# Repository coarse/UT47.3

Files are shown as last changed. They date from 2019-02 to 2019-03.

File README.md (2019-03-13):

# UT47.3
STM32 40% Keyboard PCB

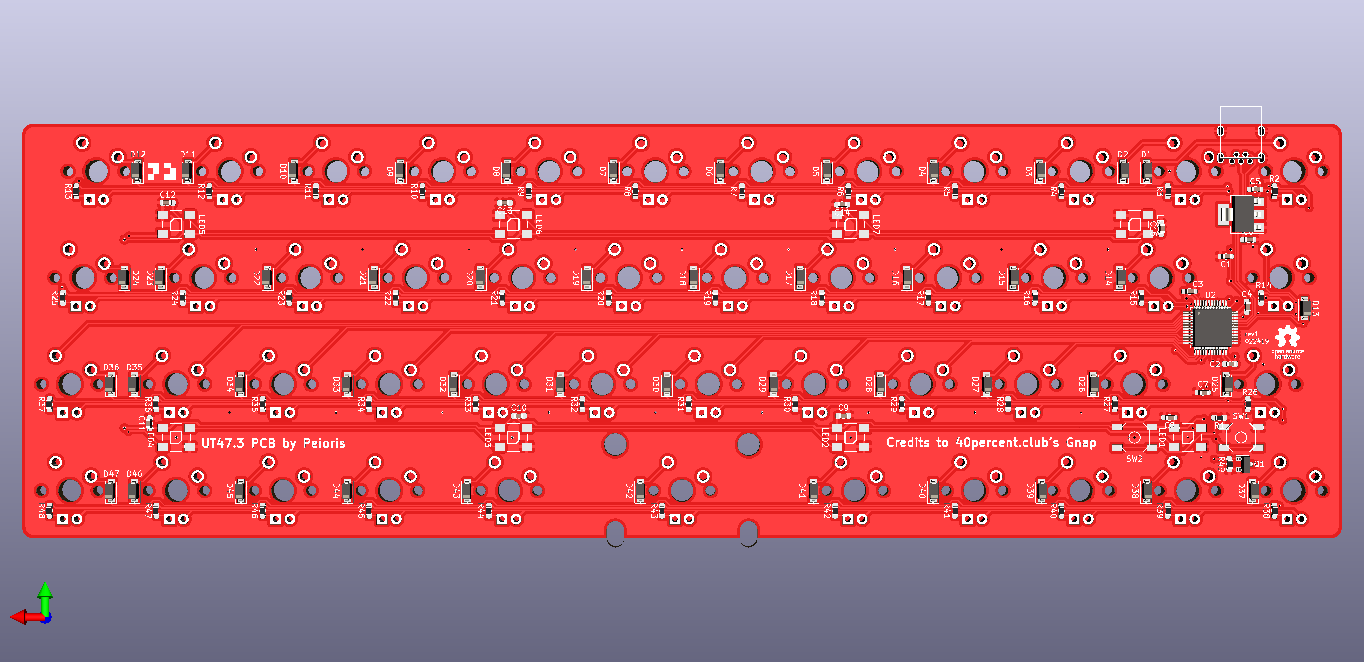
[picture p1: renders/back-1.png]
Render


Keyboard Layout Editor layout: [Layout](http://www.keyboard-layout-editor.com/#/gists/ddc8fda154c2c93ac26e38cd5da5988e)

Made with permission from [KeyHive](https://keyhive.xyz/).

The design is inspired by 40percent.club's Gnap keyboard, which is licensed under [CC BY-SA 4.0](https://creativecommons.org/licenses/by-sa/4.0/).



## Notes

At the moment, UT 47.3 is not compatible with most UT47.2 and UT47 cases. A number of differences from the two other PCBs are as follow:

1. USB port location
  - UT47.3's USB port is located at the top left part of the case. UT47 and UT47.2's USB port is located at the top right part of the case. This will be fixed in another revision
  
2. ARM Microcontroller
  - Unlike UT47 and UT47.2, UT47.3 uses an ARM microcontroller instead of an AVR microcontroller. Specifically, the UT47.3 uses an STM32F072 microcontroller due to not needing an external crystal to use it as an HID keyboard device which keeps costs low.
  
2. Reset switch location/s
  - UT47.3, powered by an STM32 chip, needs two physical switches for reset and entering DFU. Because of that, the location of the switches on the UT47.3 are differnet.
  
3. RGB underglow LED
  - UT47.3 was meant to be a budget PCB therefore the number of underglow LEDs were reduced to 8.
  
4. Single color backlight
  - UT47.3 introduces a simple single-zone backlighting.

5. Non-hotswap
  - Because backlighting is present, using hotswap modules is not an option for this PCB.

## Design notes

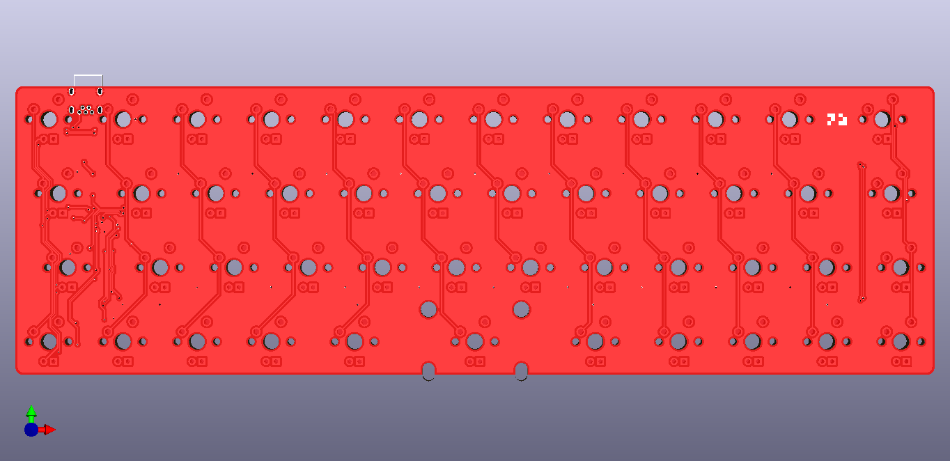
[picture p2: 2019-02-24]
renders/front-1.png

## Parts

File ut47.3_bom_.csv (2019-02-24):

Component | Description | Part | References | Value | Footprint | Quantity Per PCB | Datasheet
1 |  | C | C2 C3 C4 C7 C9 C11 C13 C14 C15 | 100nF | C_0603_1608Metric_Pad1.05x0.95mm_HandSolder | 9
2 |  | C | C5 C6 | 10uF | C_0603_1608Metric_Pad1.05x0.95mm_HandSolder | 2
3 |  | C | C1 C8 C10 C12 | 4.7uF | C_0603_1608Metric_Pad1.05x0.95mm_HandSolder | 4
4 |  | D | D1 D2 D3 D4 D5 D6 D7 D8 D9 D10 D11 D12 D13 D14 D15 D16 D17 D18 D19 D20 D21 D22 D23 D24 D25 D26 D27 D28 D29 D30 D31 D32 D33 D34 D35 D36 D37 D38 D39 D40 D41 D42 D43 D44 D45 D46 D47 | D | D_SOD-123 | 47
5 | RGB LED with integrated controller | WS2812B | LED1 LED2 LED3 LED4 LED5 LED6 LED7 LED8 | WS2812B | WS2812B | 8
6 |  | MX-1.25U | MX13 MX24 MX41 MX43 | MX-1.25U | MXOnly-1.25U | 4
7 |  | MX-1.5U | MX12 MX25 | MX-1.5U | MXOnly-1.5U | 2
8 |  | MX-1U | MX1 MX2 MX3 MX4 MX5 MX6 MX7 MX8 MX9 MX10 MX11 MX14 MX15 MX16 MX17 MX18 MX19 MX20 MX21 MX22 MX23 MX26 MX27 MX28 MX29 MX30 MX31 MX32 MX33 MX34 MX35 MX36 MX37 MX38 MX39 MX40 MX44 MX45 MX46 MX47 | MX-1U | MXOnly-1U | 40
9 |  | MX-2U | MX42 | MX-2U | MXOnly-2U-ReversedStabilizers | 1
10 | 0.2A Ic, 40V Vce, Small Signal NPN Transistor, SOT-23 | MMBT3904 | Q1 | MMBT3904 | SOT-23 | 1 | https://www.fairchildsemi.com/datasheets/2N/2N3904.pdf
11 |  | R | R1 R49 | 10k | R_0603_1608Metric_Pad1.05x0.95mm_HandSolder | 2
12 |  | R | R2 R3 R4 R5 R6 R7 R8 R9 R10 R11 R12 R13 R14 R15 R16 R17 R18 R19 R20 R21 R22 R23 R24 R25 R26 R27 R28 R29 R30 R31 R32 R33 R34 R35 R36 R37 R38 R39 R40 R41 R42 R43 R44 R45 R46 R47 R48 | 470 | R_0603_1608Metric_Pad1.05x0.95mm_HandSolder | 47
13 |  | SW | SW1 SW2 | K2-1187SQ-A4SW-06 | K2-1187SQ-A4SW-06 | 2
14 |  | LDO_REG | U1 | LD1117AG-33-AA3-A-R | SOT-223 | 1
15 | ARM Cortex-M0 MCU, 128KB flash, 16KB RAM, 48MHz, 2-3.6V, 37 GPIO, LQFP-48 | STM32F072CBTx | U2 | STM32F072CBTx | LQFP-48_7x7mm_P0.5mm | 1 | http://www.st.com/st-web-ui/static/active/en/resource/technical/document/datasheet/DM00090510.pdf
16 |  | USB_mini_micro_B | USB1 | USB_mini_micro_B | USB-Mini-B_ LCSC-C46398 | 1
Component Groups: | 16
Component Count: | 172
Fitted Components: | 172
Number of PCBs: | 1
Total components: | 172
Schematic Version:
Schematic Date:
BoM Date: | 2/24/2019 9:29:57 PM
Schematic Source: | E:\Desktop\Peioris Boards\keyboard works\UT47.3\ut47.3.sch
KiCad Version: | Eeschema (5.0.1)-4

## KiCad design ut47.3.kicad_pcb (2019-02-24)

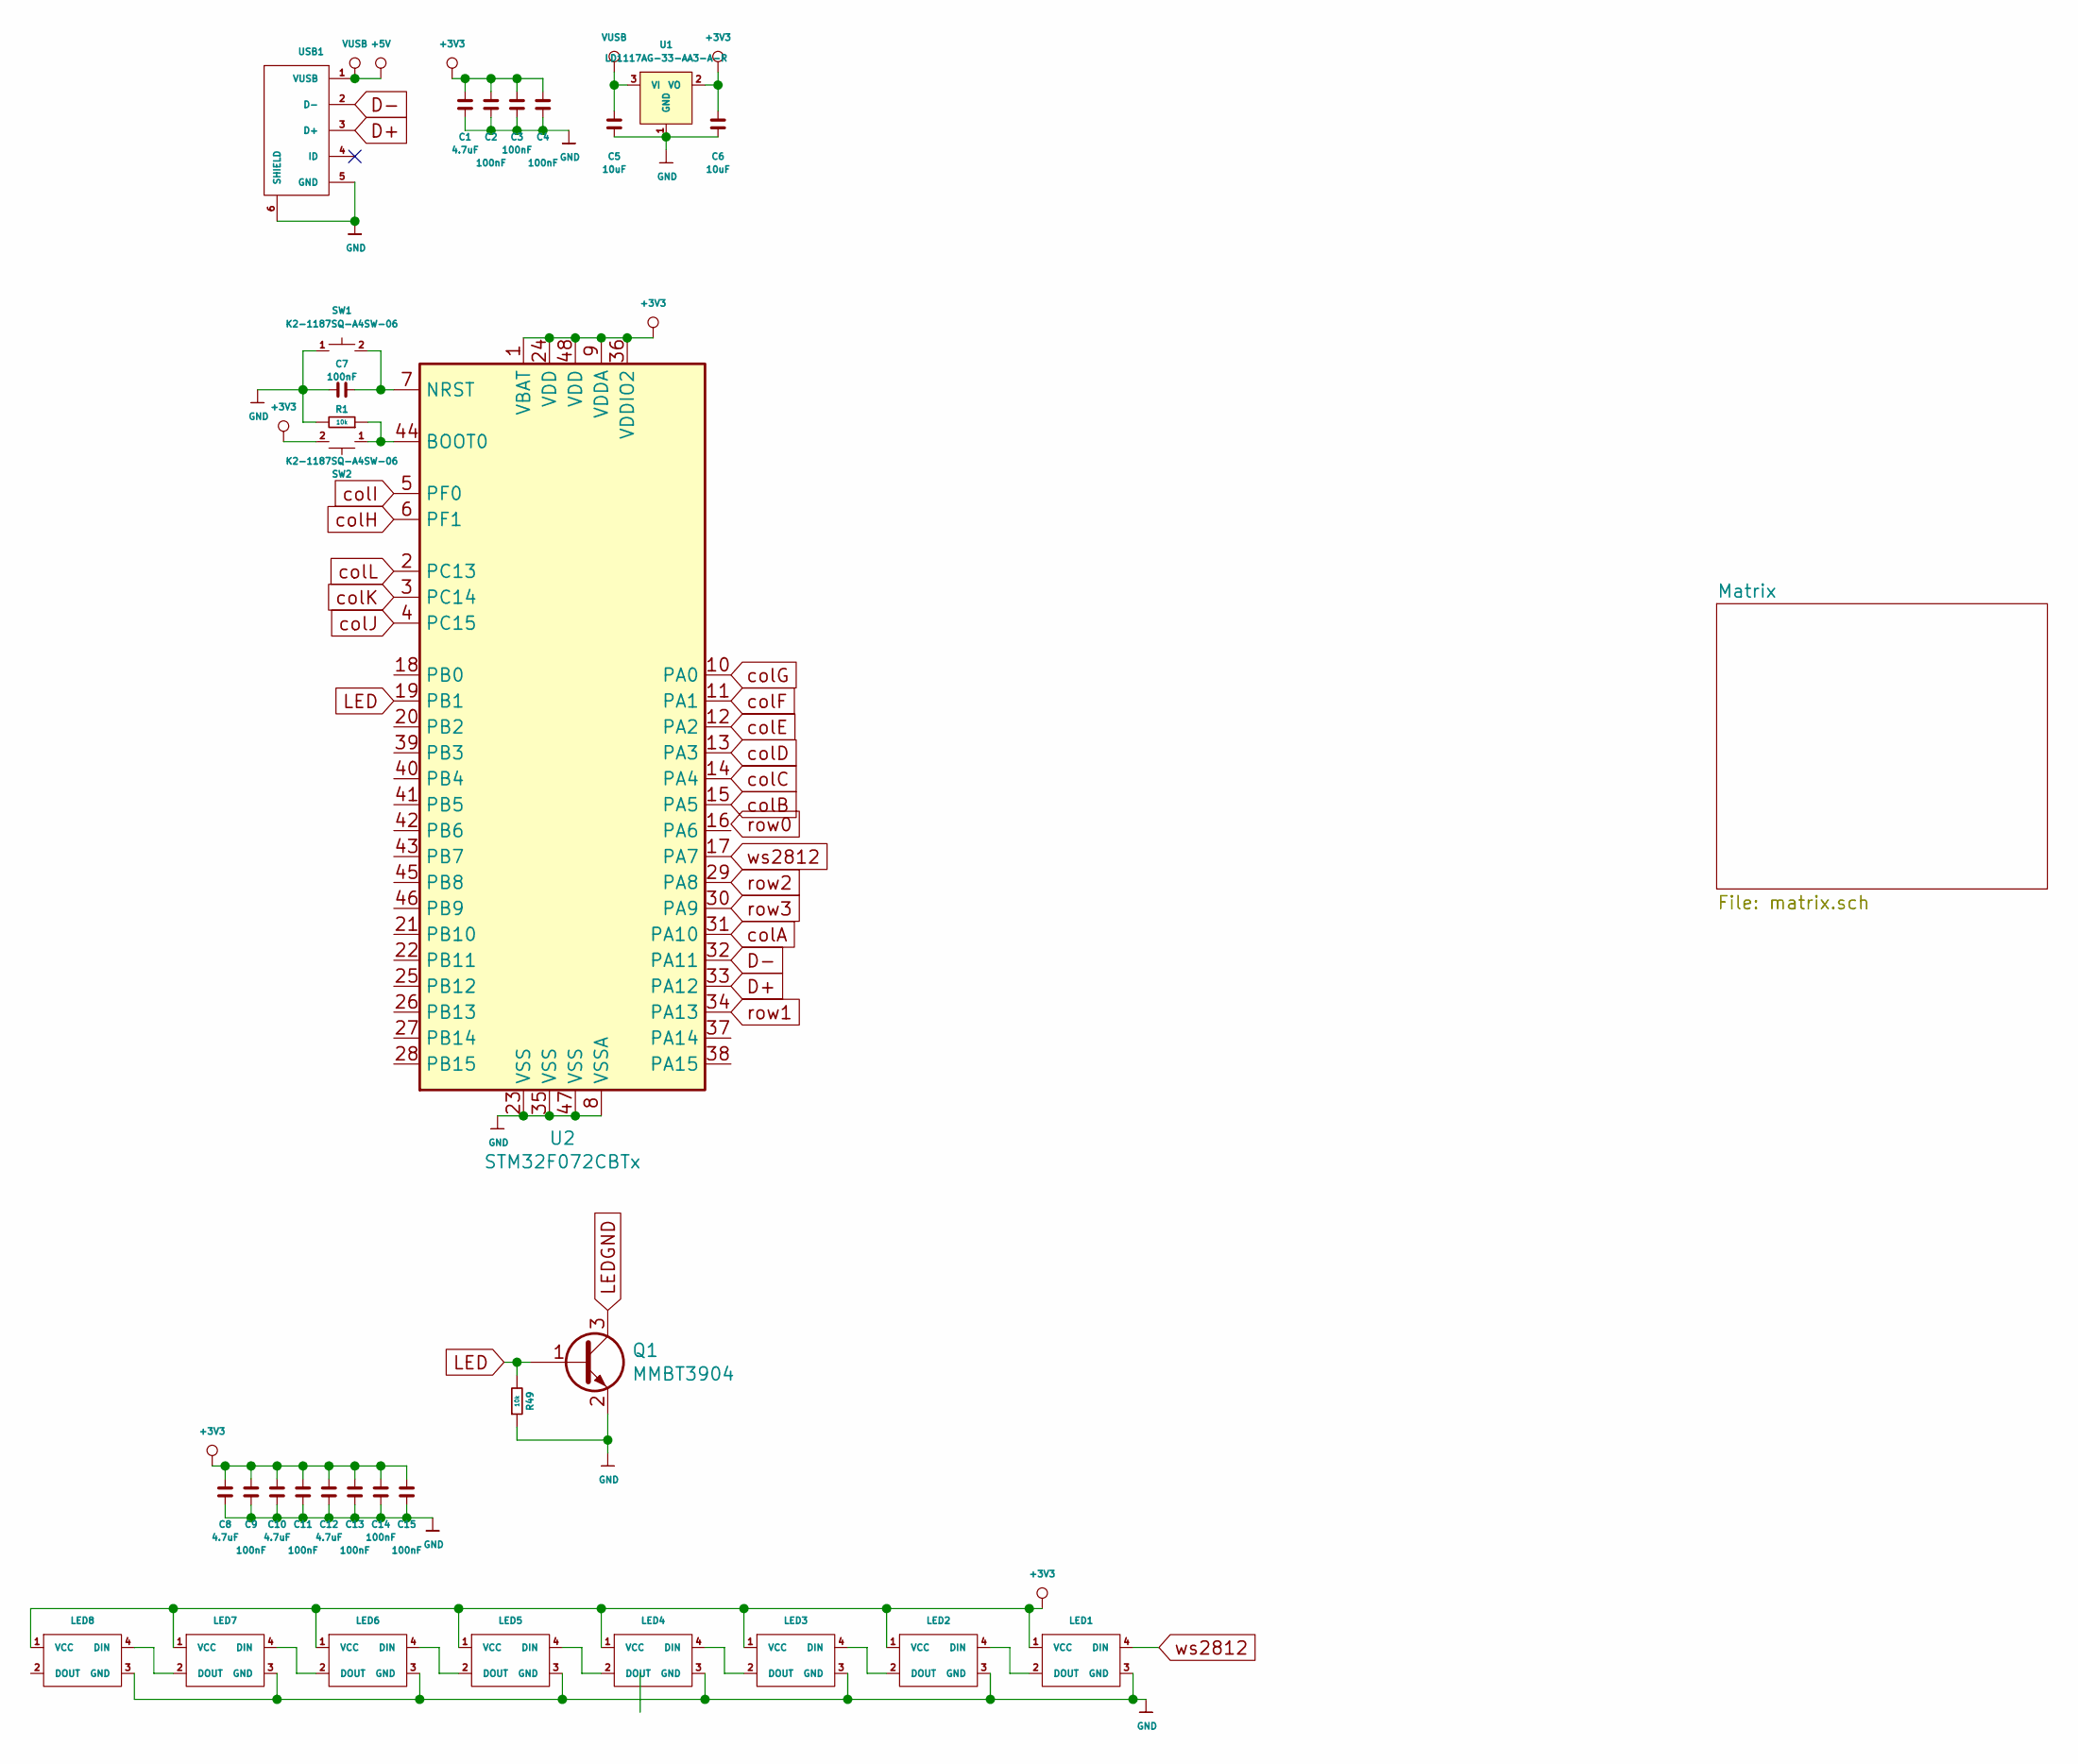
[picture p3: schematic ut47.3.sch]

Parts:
C1, C8, C10, C12: 4.7uF; C_0603_1608Metric_Pad1.05x0.95mm_HandSolder
C2, C3, C4, C7, C9, C11, C13, C14, C15: 100nF; C_0603_1608Metric_Pad1.05x0.95mm_HandSolder
C5, C6: 10uF; C_0603_1608Metric_Pad1.05x0.95mm_HandSolder
LED1, LED2, LED3, LED4, LED5, LED6, LED7, LED8: WS2812B
Q1: MMBT3904; SOT-23
R1, R49: 10k; R_0603_1608Metric_Pad1.05x0.95mm_HandSolder
SW1, SW2: K2-1187SQ-A4SW-06
U1: LD1117AG-33-AA3-A-R; SOT-223
U2: STM32F072CBTx; LQFP-48_7x7mm_P0.5mm
USB1: USB_mini_micro_B; USB-Mini-B_ LCSC-C46398

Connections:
+3V3: C1.1, C2.1, C3.1, C4.1, C6.1, C8.1, C9.1, C10.1, C11.1, C12.1, C13.1, C14.1, C15.1, LED1.1 (VCC), LED2.1 (VCC), LED3.1 (VCC), LED4.1 (VCC), LED5.1 (VCC), LED6.1 (VCC), LED7.1 (VCC), LED8.1 (VCC), SW2.2, U1.2 (VO), U2.1 (VBAT), U2.9 (VDDA), U2.24 (VDD), U2.36 (VDDIO2), U2.48 (VDD)
+5V: C5.2, U1.3 (VI), USB1.1 (VUSB); also elsewhere on the board
D+: U2.33 (PA12), USB1.3 (D+)
D-: U2.32 (PA11), USB1.2 (D-)
GND: C1.2, C2.2, C3.2, C4.2, C5.1, C6.2, C7.1, C8.2, C9.2, C10.2, C11.2, C12.2, C13.2, C14.2, C15.2, LED1.3 (GND), LED2.3 (GND), LED3.3 (GND), LED4.3 (GND), LED5.3 (GND), LED6.3 (GND), LED7.3 (GND), LED8.3 (GND), Q1.2 (E), R1.1, R49.2, SW1.1, U1.1 (GND), U2.8 (VSSA), U2.23 (VSS), U2.35 (VSS), U2.47 (VSS), USB1.5 (GND), USB1.6 (SHIELD)
LED: Q1.1 (B), R49.1, U2.19 (PB1)
LEDGND: Q1.3 (C); also elsewhere on the board
unnamed: C7.2, SW1.2, U2.7 (NRST)
unnamed: LED1.2 (DOUT), LED2.4 (DIN)
unnamed: LED2.2 (DOUT), LED3.4 (DIN)
unnamed: LED3.2 (DOUT), LED4.4 (DIN)
unnamed: LED4.2 (DOUT), LED5.4 (DIN)
unnamed: LED5.2 (DOUT), LED6.4 (DIN)
unnamed: LED6.2 (DOUT), LED7.4 (DIN)
unnamed: LED7.2 (DOUT), LED8.4 (DIN)
unnamed: R1.2, SW2.1, U2.44 (BOOT0)
colA: U2.31 (PA10); also elsewhere on the board
colB: U2.15 (PA5); also elsewhere on the board
colC: U2.14 (PA4); also elsewhere on the board
colD: U2.13 (PA3); also elsewhere on the board
colE: U2.12 (PA2); also elsewhere on the board
colF: U2.11 (PA1); also elsewhere on the board
colG: U2.10 (PA0); also elsewhere on the board
colH: U2.6 (PF1); also elsewhere on the board
colI: U2.5 (PF0); also elsewhere on the board
colJ: U2.4 (PC15); also elsewhere on the board
colK: U2.3 (PC14); also elsewhere on the board
colL: U2.2 (PC13); also elsewhere on the board
row1: U2.34 (PA13); also elsewhere on the board
row2: U2.29 (PA8); also elsewhere on the board
row3: U2.30 (PA9); also elsewhere on the board
ws2812: LED1.4 (DIN), U2.17 (PA7)

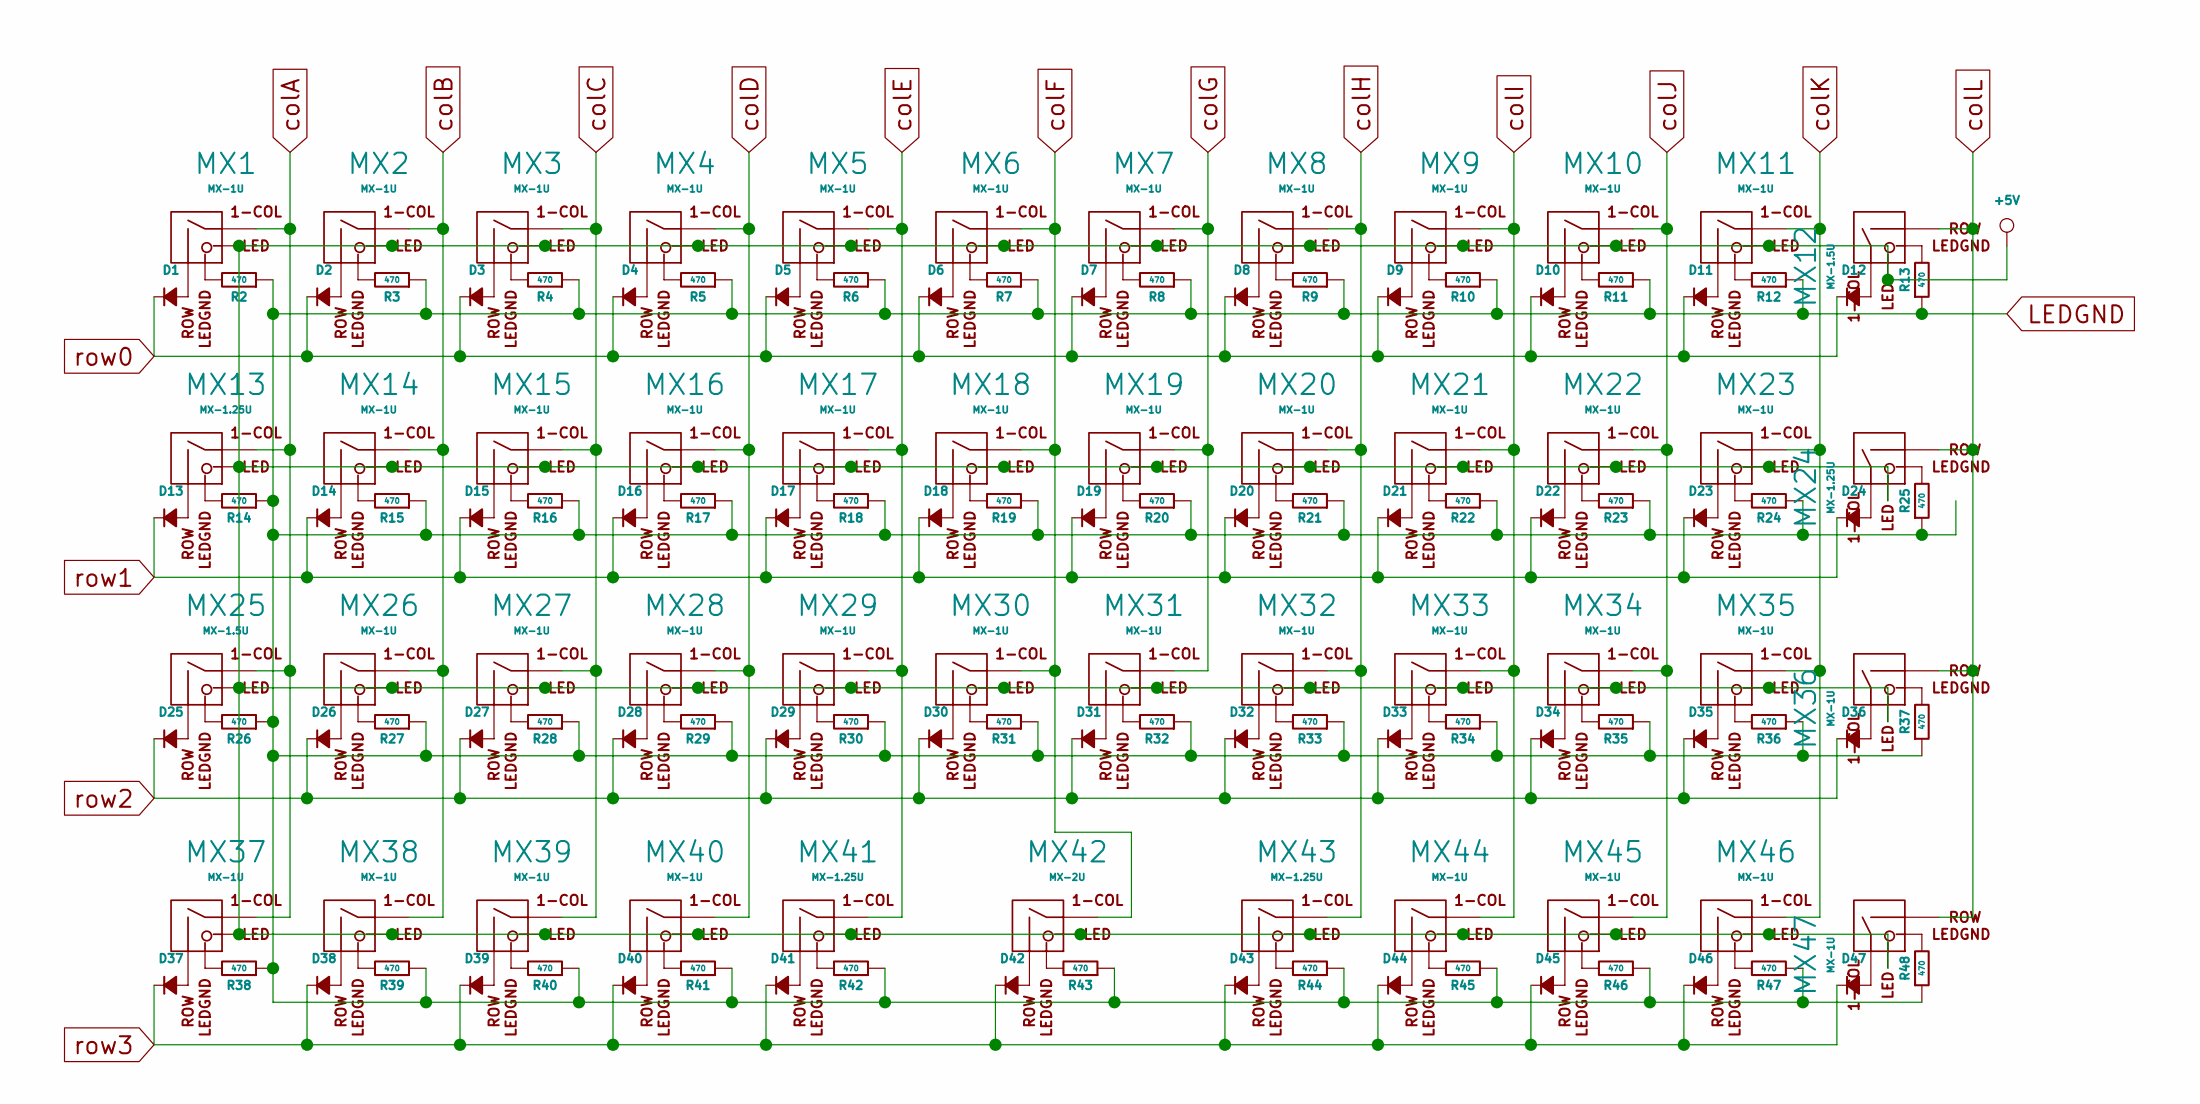
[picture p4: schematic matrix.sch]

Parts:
D1, D2, D3, D4, D5, D6, D7, D8, D9, D10, D11, D12, D13, D14, D15, D16, D17, D18, D19, D20, D21, D22, D23, D24, D25, D26, D27, D28, D29, D30, D31, D32, D33, D34, D35, D36, D37, D38, D39, D40, D41, D42, D43, D44, D45, D46, D47: D; D_SOD-123
MX1, MX2, MX3, MX4, MX5, MX6, MX7, MX8, MX9, MX10, MX11, MX14, MX15, MX16, MX17, MX18, MX19, MX20, MX21, MX22, MX23, MX26, MX27, MX28, MX29, MX30, MX31, MX32, MX33, MX34, MX35, MX36, MX37, MX38, MX39, MX40, MX44, MX45, MX46, MX47: MX-1U; MXOnly-1U
MX12, MX25: MX-1.5U; MXOnly-1.5U
MX13, MX24, MX41, MX43: MX-1.25U; MXOnly-1.25U
MX42: MX-2U; MXOnly-2U-ReversedStabilizers
R2, R3, R4, R5, R6, R7, R8, R9, R10, R11, R12, R13, R14, R15, R16, R17, R18, R19, R20, R21, R22, R23, R24, R25, R26, R27, R28, R29, R30, R31, R32, R33, R34, R35, R36, R37, R38, R39, R40, R41, R42, R43, R44, R45, R46, R47, R48: 470; R_0603_1608Metric_Pad1.05x0.95mm_HandSolder

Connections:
+5V: MX1.3 (LED), MX2.3 (LED), MX3.3 (LED), MX4.3 (LED), MX5.3 (LED), MX6.3 (LED), MX7.3 (LED), MX8.3 (LED), MX9.3 (LED), MX10.3 (LED), MX11.3 (LED), MX12.3 (LED), MX13.3 (LED), MX14.3 (LED), MX15.3 (LED), MX16.3 (LED), MX17.3 (LED), MX18.3 (LED), MX19.3 (LED), MX20.3 (LED), MX21.3 (LED), MX22.3 (LED), MX23.3 (LED), MX24.3 (LED), MX25.3 (LED), MX26.3 (LED), MX27.3 (LED), MX28.3 (LED), MX29.3 (LED), MX30.3 (LED), MX31.3 (LED), MX32.3 (LED), MX33.3 (LED), MX34.3 (LED), MX35.3 (LED), MX36.3 (LED), MX37.3 (LED), MX38.3 (LED), MX39.3 (LED), MX40.3 (LED), MX41.3 (LED), MX42.3 (LED), MX43.3 (LED), MX44.3 (LED), MX45.3 (LED), MX46.3 (LED), MX47.3 (LED); also elsewhere on the board
LEDGND: R2.2, R3.2, R4.2, R5.2, R6.2, R7.2, R8.2, R9.2, R10.2, R11.2, R12.2, R13.2, R14.2, R15.2, R16.2, R17.2, R18.2, R19.2, R20.2, R21.2, R22.2, R23.2, R24.2, R25.2, R26.2, R27.2, R28.2, R29.2, R30.2, R31.2, R32.2, R33.2, R34.2, R35.2, R36.2, R37.2, R38.2, R39.2, R40.2, R41.2, R42.2, R43.2, R44.2, R45.2, R46.2, R47.2, R48.2; also elsewhere on the board
unnamed: D1.2, MX1.2 (ROW)
unnamed: D2.2, MX2.2 (ROW)
unnamed: D3.2, MX3.2 (ROW)
unnamed: D4.2, MX4.2 (ROW)
unnamed: D5.2, MX5.2 (ROW)
unnamed: D6.2, MX6.2 (ROW)
unnamed: D7.2, MX7.2 (ROW)
unnamed: D8.2, MX8.2 (ROW)
unnamed: D9.2, MX9.2 (ROW)
unnamed: D10.2, MX10.2 (ROW)
unnamed: D11.2, MX11.2 (ROW)
unnamed: D12.2, MX12.1 (COL)
unnamed: D13.2, MX13.2 (ROW)
unnamed: D14.2, MX14.2 (ROW)
unnamed: D15.2, MX15.2 (ROW)
unnamed: D16.2, MX16.2 (ROW)
unnamed: D17.2, MX17.2 (ROW)
unnamed: D18.2, MX18.2 (ROW)
unnamed: D19.2, MX19.2 (ROW)
unnamed: D20.2, MX20.2 (ROW)
unnamed: D21.2, MX21.2 (ROW)
unnamed: D22.2, MX22.2 (ROW)
unnamed: D23.2, MX23.2 (ROW)
unnamed: D24.2, MX24.1 (COL)
unnamed: D25.2, MX25.2 (ROW)
unnamed: D26.2, MX26.2 (ROW)
unnamed: D27.2, MX27.2 (ROW)
unnamed: D28.2, MX28.2 (ROW)
unnamed: D29.2, MX29.2 (ROW)
unnamed: D30.2, MX30.2 (ROW)
unnamed: D31.2, MX31.2 (ROW)
unnamed: D32.2, MX32.2 (ROW)
unnamed: D33.2, MX33.2 (ROW)
unnamed: D34.2, MX34.2 (ROW)
unnamed: D35.2, MX35.2 (ROW)
unnamed: D36.2, MX36.1 (COL)
unnamed: D37.2, MX37.2 (ROW)
unnamed: D38.2, MX38.2 (ROW)
unnamed: D39.2, MX39.2 (ROW)
unnamed: D40.2, MX40.2 (ROW)
unnamed: D41.2, MX41.2 (ROW)
unnamed: D42.2, MX42.2 (ROW)
unnamed: D43.2, MX43.2 (ROW)
unnamed: D44.2, MX44.2 (ROW)
unnamed: D45.2, MX45.2 (ROW)
unnamed: D46.2, MX46.2 (ROW)
unnamed: D47.2, MX47.1 (COL)
unnamed: MX1.4 (LEDGND), R2.1
unnamed: MX2.4 (LEDGND), R3.1
unnamed: MX3.4 (LEDGND), R4.1
unnamed: MX4.4 (LEDGND), R5.1
unnamed: MX5.4 (LEDGND), R6.1
unnamed: MX6.4 (LEDGND), R7.1
unnamed: MX7.4 (LEDGND), R8.1
unnamed: MX8.4 (LEDGND), R9.1
unnamed: MX9.4 (LEDGND), R10.1
unnamed: MX10.4 (LEDGND), R11.1
unnamed: MX11.4 (LEDGND), R12.1
unnamed: MX12.4 (LEDGND), R13.1
unnamed: MX13.4 (LEDGND), R14.1
unnamed: MX14.4 (LEDGND), R15.1
unnamed: MX15.4 (LEDGND), R16.1
unnamed: MX16.4 (LEDGND), R17.1
unnamed: MX17.4 (LEDGND), R18.1
unnamed: MX18.4 (LEDGND), R19.1
unnamed: MX19.4 (LEDGND), R20.1
unnamed: MX20.4 (LEDGND), R21.1
unnamed: MX21.4 (LEDGND), R22.1
unnamed: MX22.4 (LEDGND), R23.1
unnamed: MX23.4 (LEDGND), R24.1
unnamed: MX24.4 (LEDGND), R25.1
unnamed: MX25.4 (LEDGND), R26.1
unnamed: MX26.4 (LEDGND), R27.1
unnamed: MX27.4 (LEDGND), R28.1
unnamed: MX28.4 (LEDGND), R29.1
unnamed: MX29.4 (LEDGND), R30.1
unnamed: MX30.4 (LEDGND), R31.1
unnamed: MX31.4 (LEDGND), R32.1
unnamed: MX32.4 (LEDGND), R33.1
unnamed: MX33.4 (LEDGND), R34.1
unnamed: MX34.4 (LEDGND), R35.1
unnamed: MX35.4 (LEDGND), R36.1
unnamed: MX36.4 (LEDGND), R37.1
unnamed: MX37.4 (LEDGND), R38.1
unnamed: MX38.4 (LEDGND), R39.1
unnamed: MX39.4 (LEDGND), R40.1
unnamed: MX40.4 (LEDGND), R41.1
unnamed: MX41.4 (LEDGND), R42.1
unnamed: MX42.4 (LEDGND), R43.1
unnamed: MX43.4 (LEDGND), R44.1
unnamed: MX44.4 (LEDGND), R45.1
unnamed: MX45.4 (LEDGND), R46.1
unnamed: MX46.4 (LEDGND), R47.1
unnamed: MX47.4 (LEDGND), R48.1
colA: MX1.1 (COL), MX13.1 (COL), MX25.1 (COL), MX37.1 (COL); also elsewhere on the board
colB: MX2.1 (COL), MX14.1 (COL), MX26.1 (COL), MX38.1 (COL); also elsewhere on the board
colC: MX3.1 (COL), MX15.1 (COL), MX27.1 (COL), MX39.1 (COL); also elsewhere on the board
colD: MX4.1 (COL), MX16.1 (COL), MX28.1 (COL), MX40.1 (COL); also elsewhere on the board
colE: MX5.1 (COL), MX17.1 (COL), MX29.1 (COL), MX41.1 (COL); also elsewhere on the board
colF: MX6.1 (COL), MX18.1 (COL), MX30.1 (COL), MX42.1 (COL); also elsewhere on the board
colG: MX7.1 (COL), MX19.1 (COL), MX31.1 (COL); also elsewhere on the board
colH: MX8.1 (COL), MX20.1 (COL), MX32.1 (COL), MX43.1 (COL); also elsewhere on the board
colI: MX9.1 (COL), MX21.1 (COL), MX33.1 (COL), MX44.1 (COL); also elsewhere on the board
colJ: MX10.1 (COL), MX22.1 (COL), MX34.1 (COL), MX45.1 (COL); also elsewhere on the board
colK: MX11.1 (COL), MX23.1 (COL), MX35.1 (COL), MX46.1 (COL); also elsewhere on the board
colL: MX12.2 (ROW), MX24.2 (ROW), MX36.2 (ROW), MX47.2 (ROW); also elsewhere on the board
row0: D1.1, D2.1, D3.1, D4.1, D5.1, D6.1, D7.1, D8.1, D9.1, D10.1, D11.1, D12.1
row1: D13.1, D14.1, D15.1, D16.1, D17.1, D18.1, D19.1, D20.1, D21.1, D22.1, D23.1, D24.1; also elsewhere on the board
row2: D25.1, D26.1, D27.1, D28.1, D29.1, D30.1, D31.1, D32.1, D33.1, D34.1, D35.1, D36.1; also elsewhere on the board
row3: D37.1, D38.1, D39.1, D40.1, D41.1, D42.1, D43.1, D44.1, D45.1, D46.1, D47.1; also elsewhere on the board

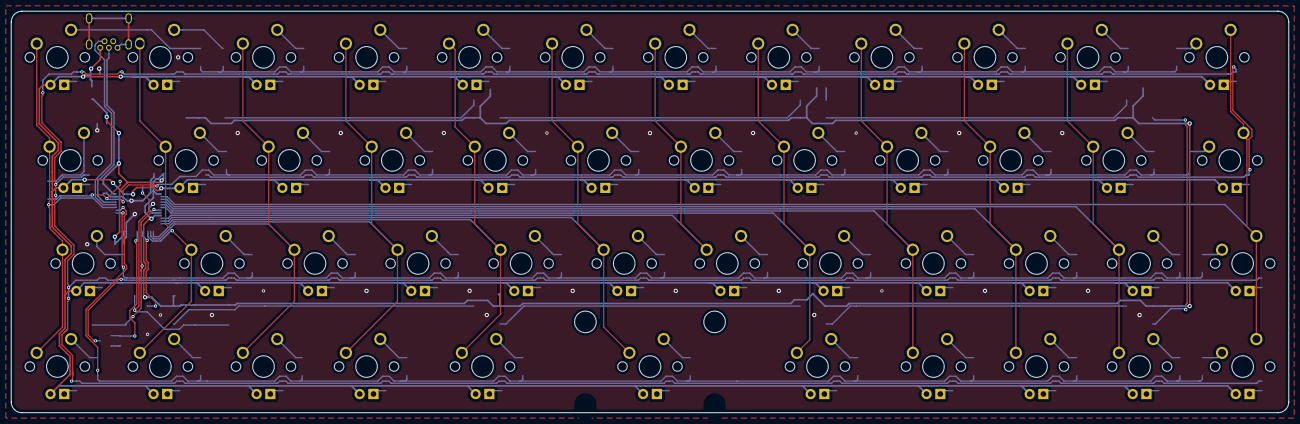
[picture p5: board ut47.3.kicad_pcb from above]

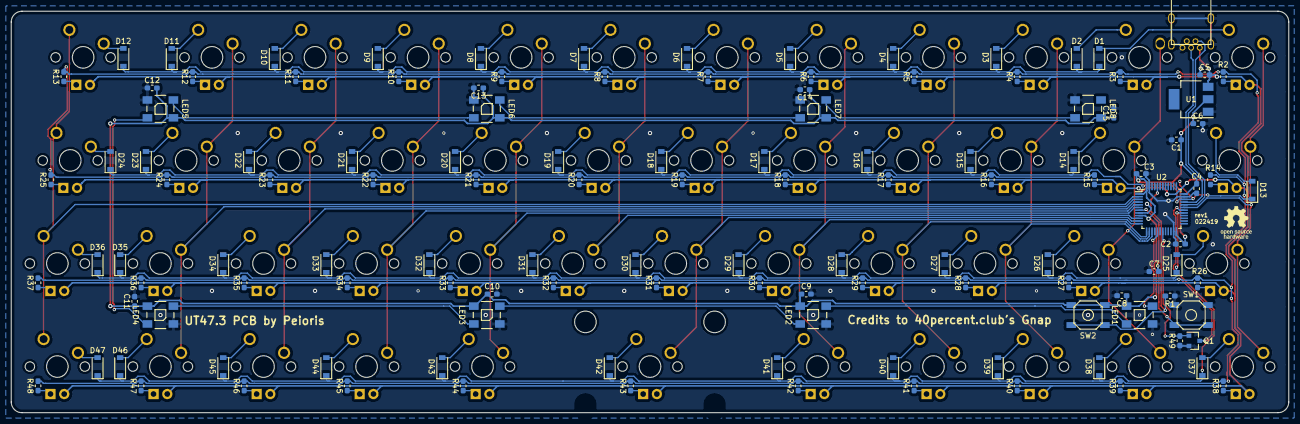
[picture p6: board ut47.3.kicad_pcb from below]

Board: 2 copper layers, 236.1 x 74.2 mm, 172 parts (125 on the bottom side), 127 nets.

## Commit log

2019-02-24 inital commit
    [matrix.sch, ut47.3.kicad_pcb, ut47.3.sch]
2019-02-24 add bom files
    [ut47.3_bom_.csv]

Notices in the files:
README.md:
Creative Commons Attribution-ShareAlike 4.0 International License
